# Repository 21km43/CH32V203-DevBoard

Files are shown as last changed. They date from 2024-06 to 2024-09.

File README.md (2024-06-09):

# CH32V203 Development Board

## Summary
Schematic and Board layout of CH32V203 Development Board. This project was created using [KiCAD 8](https://www.kicad.org/).

## MCU
[CH32V203C8T6](https://www.wch-ic.com/products/CH32V203.html)  
144MHz, 20KB RAM, 64KB ROM  

## Features
* CH32V203C8T6 RISC-V
* `144 MHz` maximum frequency, `64 KB` of Flash memory, `20 KB` of SRAM
* `8 MHz` crystal (High-Speed Enternal Clock)
* `32.768 KHz` crystal (Low-Speed External Clock)
* Frequency deviation of crystal has been tested (on FR-4 board with a thickness of 1.6 mm)
* White LED for `PC13`
* 2x20 side pins
* Size: `50.80 mm x 20.32 mm`
* USB Device (Type-C)
  * PA11 USB1_DM
  * PA12 USB1_DP
* USB Host (Type-C)
  * PB6 USB2_DM
  * PB7 USB2_DP
* All component parameters are already set for [JLCPCB](https://jlcpcb.com). (Thanks for [Fabrication Toolkit](https://github.com/bennymeg/Fabrication-Toolkit))
  * Tooling Hole for SMT Assembly has been added.

## Solder jumpers
* JP1 ... If this jumper is opened, 3.3V cannot be output from the USB or 5V pins through the LDO regulator, and power must be supplied to the MCU from 3.3V. Instead, the quiescent current of the LDO regulator can be set to 0, which optimizes power consumption.
* JP2 ... Shorting this jumper disables the back-flow protection from the 5V pin to the USB input; short it when you want to output 5V from the USB to 5V with no voltage drop or when you want to use the 5V pin to power the USB2 output. Do not supply power from both the 5V pin and USB while shorted. Note that shorting this pin will increase current consumption by about 0.1~0.2mA due to the pull-down resistor on the CC pin.
* JP3 ... Shorting all of these jumpers changes the function of USB2 from Host to Device and allows it to receive power from USB2. In this case, it is not recommended to use USB1 and USB2 at the same time (because of the risk of short circuits if the voltages of USB1 and USB2 are different)

## Parts List
You can see parts list from the BOM below.  
[Parts List](/production/bom.csv)

## Schematic and Board image
[Board schematic](CH32V203-DevBoard.pdf)  
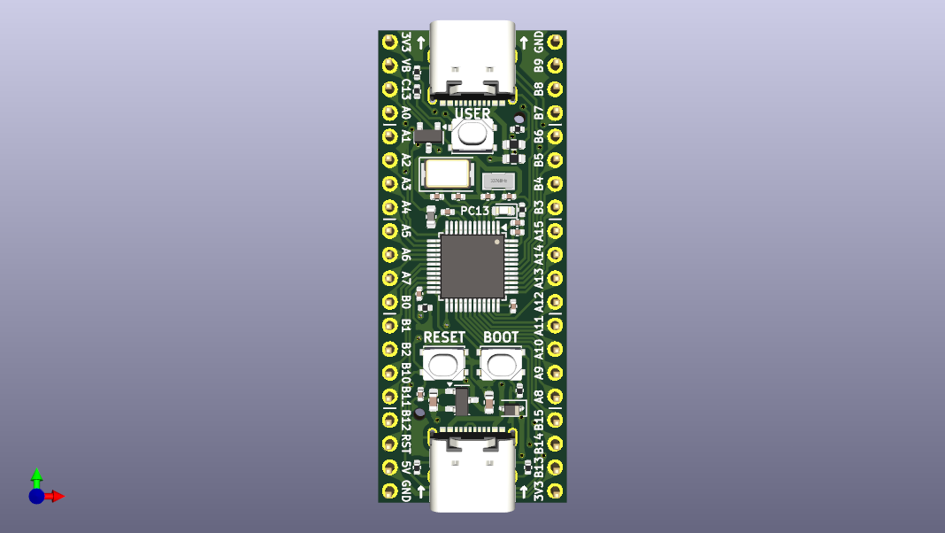
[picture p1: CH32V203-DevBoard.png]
Board Image


## LICENSE
[MIT LICENSE](/LICENSE)  
You may use it freely for personal use, but if you wish to use it for commercial purposes, I would appreciate it if you could contact me.

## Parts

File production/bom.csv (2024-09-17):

Designator | Footprint | Quantity | Value | LCSC Part #
C1, C2 | 0402 | 2 | 15pF | C1548
C10, C5, C6, C7, C8, C9 | 0402 | 6 | 100nF | C1525
C11, C12 | 0603 | 2 | 1uF | C15849
C3, C4 | 0402 | 2 | 22pF | C1555
D1 | D_SOD-323 | 1 | 1N5819WS | C191023
D2 | SOT-23 | 1 | BAT54C,215 | C37704
FB1 | 0603 | 1 | FerriteBead | C1002
J1, J2 | USB_C_Receptacle_XKB_U262-16XN-4BVC11 | 2 | USB_C_Receptacle_USB2.0_16P | C2988369
LED1 | 0603 | 1 | LED | C2290
R1, R2, R8 | 0402 | 3 | 10kΩ | C25744
R10, R11, R3, R4, R5 | 0402 | 5 | 5.1kΩ | C25905
R6, R7 | 0603 | 2 | 56kΩ | C23206
SW1, SW2, SW3 | SW_SPST_PTS810 | 3 | SW_Push | C115360
U1 | LQFP-48_7x7mm_P0.5mm | 1 | CH32V203C8T6 | C3001172
U2 | SOT-23-3 | 1 | XC6206P332MR | C5446
XTAL1 | Crystal_SMD_3215-2Pin_3.2x1.5mm | 1 | 32.768KHz | C32346
XTAL2 | Crystal_SMD_5032-2Pin_5.0x3.2mm | 1 | 8MHz | C115962

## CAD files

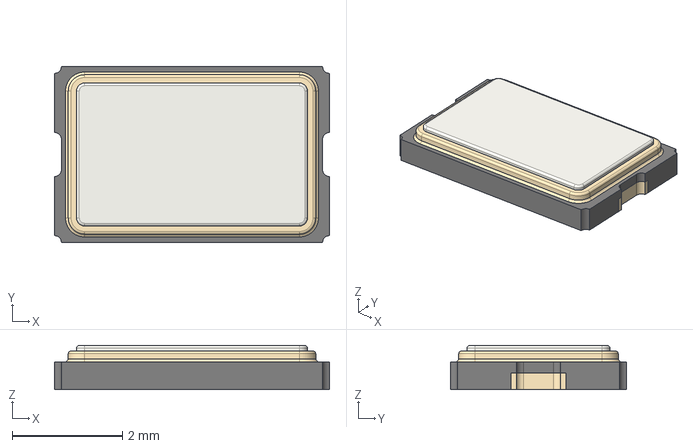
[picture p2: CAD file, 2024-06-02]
3d/5032_crystal_oscillator.step
5.00 x 3.20 x 0.8 mm

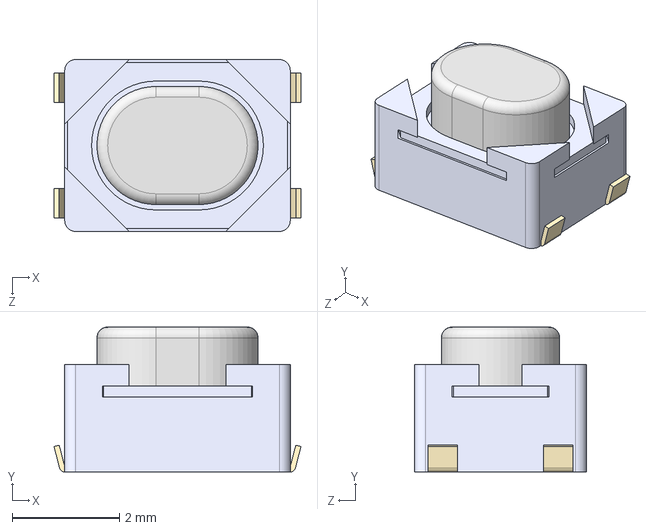
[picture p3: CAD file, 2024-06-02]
3d/PTS810.STEP
4.60 x 2.70 x 3.20 mm

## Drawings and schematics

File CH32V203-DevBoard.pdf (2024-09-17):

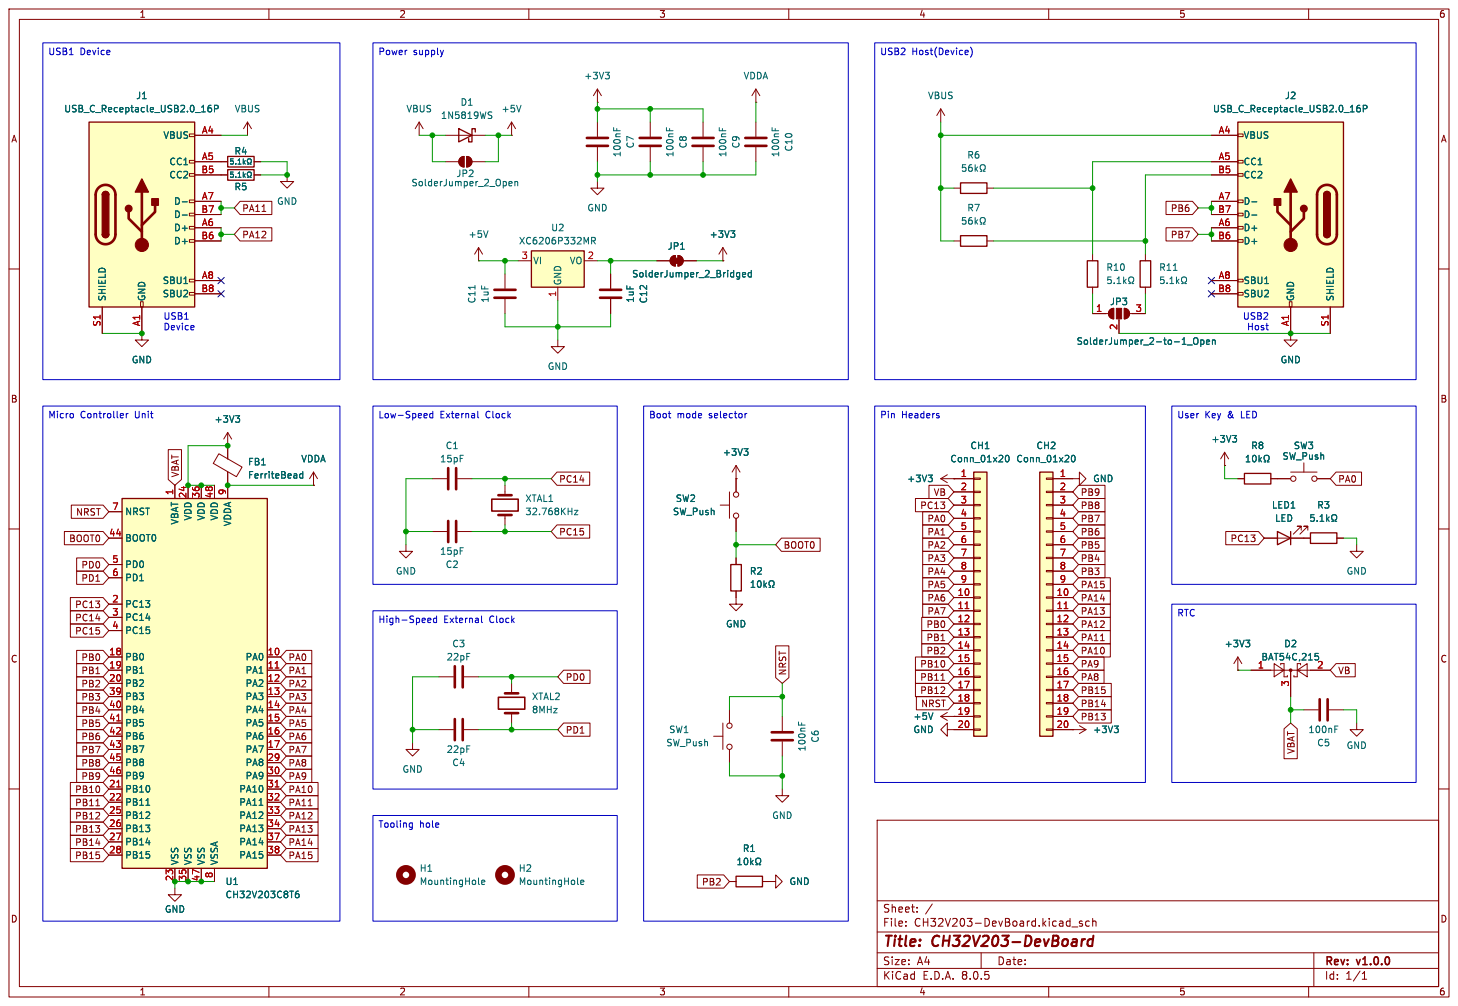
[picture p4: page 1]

1 PA0 10 PA1 11 PA2 12 PA3 13 PA4 14 PA5 15 PA6 16 PA7 17 PB0 18 PB1 19 PC13 2 PB2 20 PB10 21 PB11 22 VSS 23 VDD 24 PB12 25 PB13 26 PB14 27 PB15 28 PA8 29 PC14 3 PA9 30 PA10 31 PA11 32 PA12 33 PA13 34 VSS 35 VDD 36 PA14 37 PA15 38 PB3 39 PC15 4 PB4 40 PB5 41 PB6 42 PB7 43 BOOT0 44 PB8 45 PB9 46 VSS 47 VDD 48 PD0 5 PD1 6 NRST 7 VSSA

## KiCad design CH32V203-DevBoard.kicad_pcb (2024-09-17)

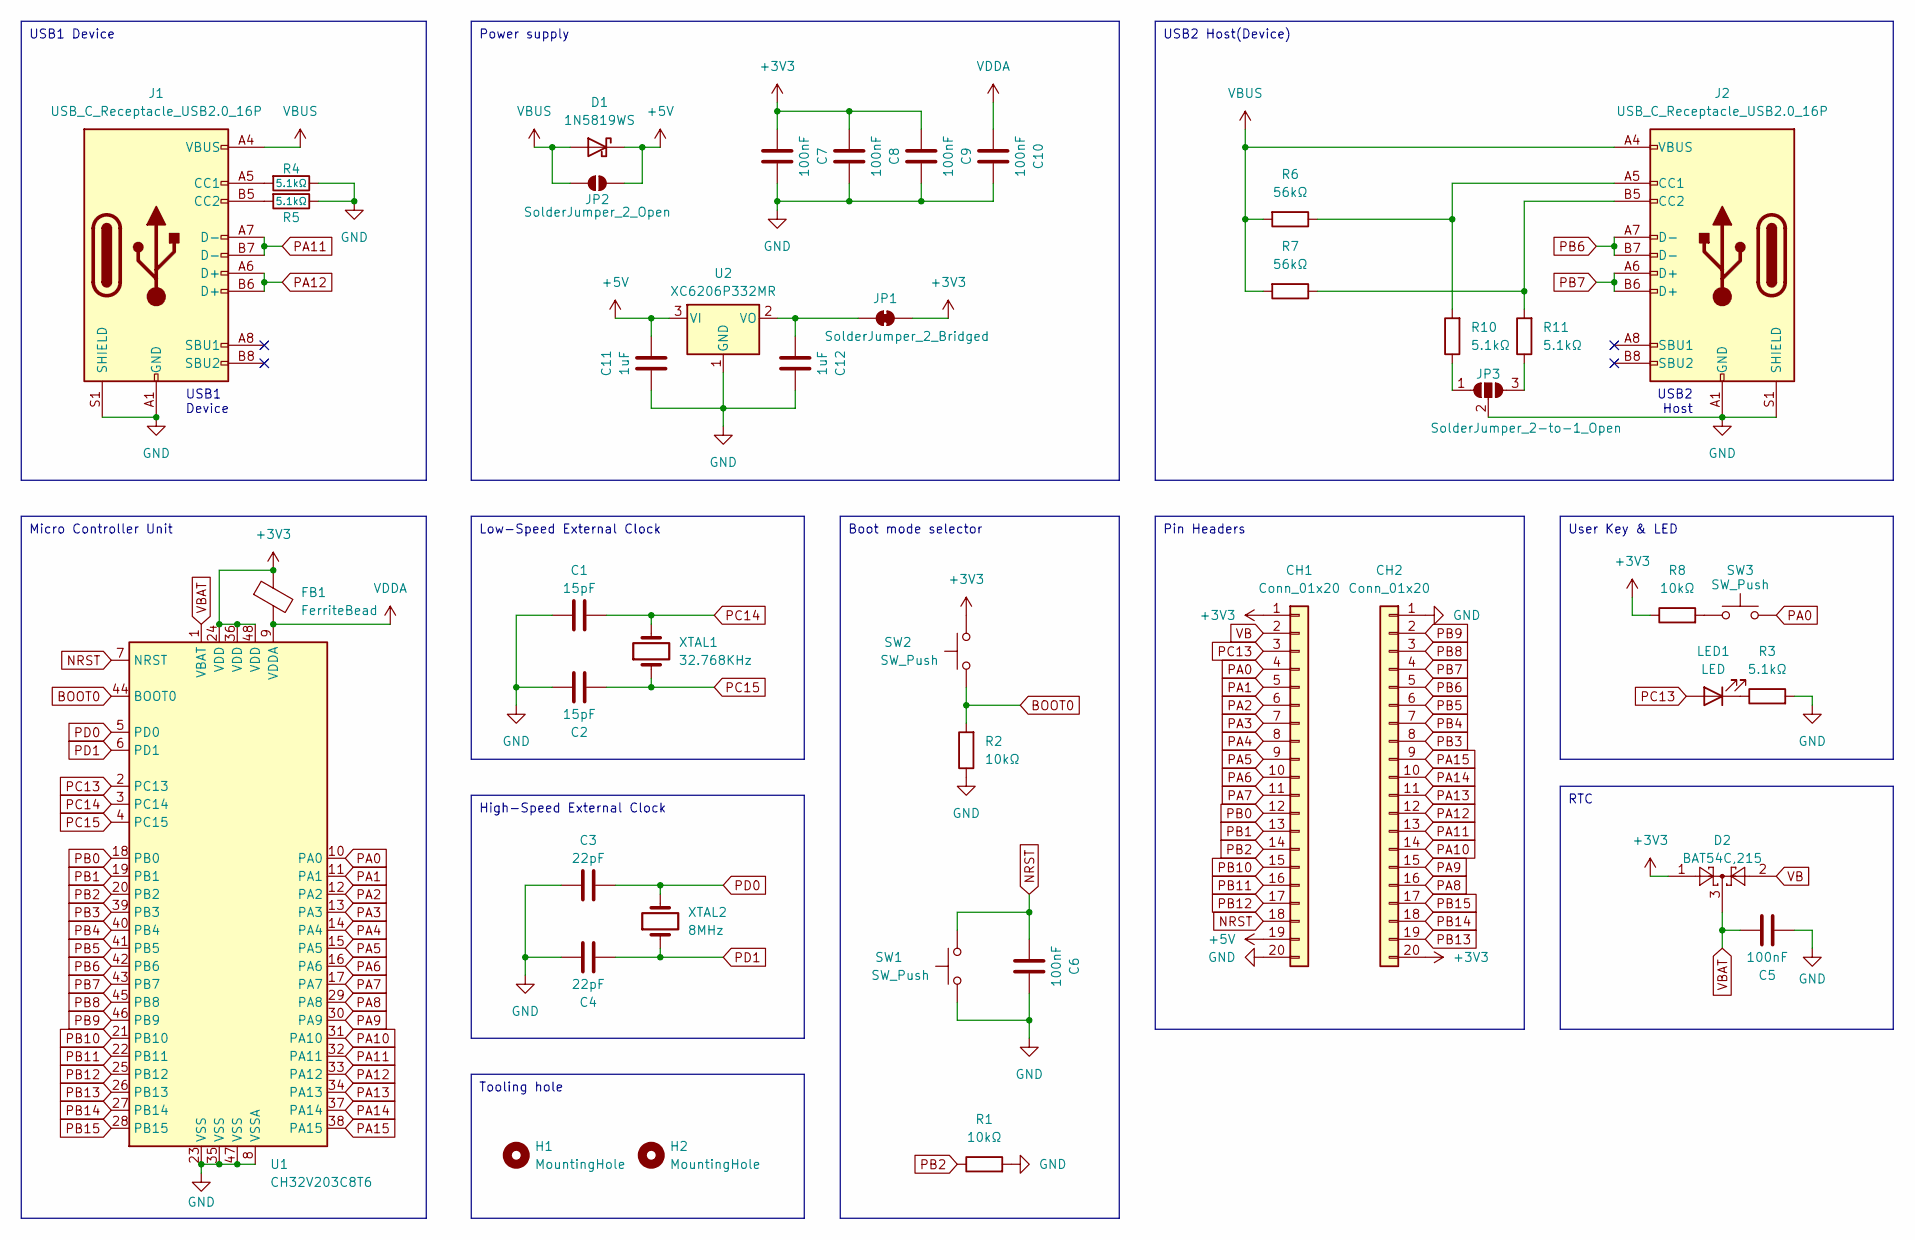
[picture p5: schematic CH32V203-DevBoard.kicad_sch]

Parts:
C1, C2: 15pF; C_0402_1005Metric; LCSC C1548
C3, C4: 22pF; C_0402_1005Metric; LCSC C1555
C5, C6, C7, C8, C9, C10: 100nF; C_0402_1005Metric; LCSC C1525
C11, C12: 1uF; C_0603_1608Metric; LCSC C15849
CH1, CH2: Conn_01x20; PinHeader_1x20_P2.54mm_Vertical
D1: 1N5819WS; D_SOD-323; LCSC C191023
D2: BAT54C,215; SOT-23; LCSC C37704
FB1: FerriteBead; L_0603_1608Metric; LCSC C1002
H1, H2: MountingHole; Tooling_Hole
J1, J2: USB_C_Receptacle_USB2.0_16P; USB_C_Receptacle_XKB_U262-16XN-4BVC11; LCSC C2988369
JP1: SolderJumper_2_Bridged; SolderJumper-2_P1.3mm_Bridged_RoundedPad1.0x1.5mm
JP2: SolderJumper_2_Open; SolderJumper-2_P1.3mm_Open_RoundedPad1.0x1.5mm
JP3: SolderJumper_2-to-1_Open; SolderJumper-2-to-1_P0.9mm_Open
LED1: LED; LED_0603_1608Metric; LCSC C2290
R1, R2, R8: 10kΩ; R_0402_1005Metric; LCSC C25744
R3, R4, R5, R10, R11: 5.1kΩ; R_0402_1005Metric; LCSC C25905
R6, R7: 56kΩ; R_0603_1608Metric; LCSC C23206
SW1, SW2, SW3: SW_Push; SW_SPST_PTS810; LCSC C115360
U1: CH32V203C8T6; LQFP-48_7x7mm_P0.5mm; LCSC C3001172
U2: XC6206P332MR; SOT-23-3; LCSC C5446
XTAL1: 32.768KHz; Crystal_SMD_3215-2Pin_3.2x1.5mm; LCSC C32346
XTAL2: 8MHz; Crystal_SMD_5032-2Pin_5.0x3.2mm; LCSC C115962

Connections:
+3V3: C7.1, C8.1, C9.1, CH1.1, CH2.20, D2.1, FB1.1, JP1.2 (B), R8.1, SW2.2, U1.24 (VDD), U1.36 (VDD), U1.48 (VDD)
+5V: C11.1, CH1.19, D1.1 (K), JP2.2 (B), U2.3 (VI)
BOOT0: R2.2, SW2.1, U1.44 (BOOT0)
GND: C1.1, C2.2, C3.1, C4.2, C5.1, C6.2, C7.2, C8.2, C9.2, C10.2, C11.2, C12.2, CH1.20, CH2.1, J1.A1 (GND), J1.A12 (GND), J1.B1 (GND), J1.B12 (GND), J1.S1 (SHIELD), J2.A1 (GND), J2.A12 (GND), J2.B1 (GND), J2.B12 (GND), J2.S1 (SHIELD), JP3.2 (C), R1.2, R2.1, R3.2, R4.1, R5.1, SW1.1, U1.8 (VSSA), U1.23 (VSS), U1.35 (VSS), U1.47 (VSS), U2.1 (GND)
NRST: C6.1, CH1.18, SW1.2, U1.7 (NRST)
unnamed: J1.A5 (CC1), R4.2
unnamed: J1.B5 (CC2), R5.2
unnamed: J2.A5 (CC1), R6.1, R10.2
unnamed: J2.B5 (CC2), R7.1, R11.2
unnamed: C12.1, JP1.1 (A), U2.2 (VO)
unnamed: JP3.1 (A), R10.1
unnamed: JP3.3 (B), R11.1
unnamed: LED1.1 (K), R3.1
unnamed: R8.2, SW3.1
PA0: CH1.4, SW3.2, U1.10 (PA0)
PA1: CH1.5, U1.11 (PA1)
PA2: CH1.6, U1.12 (PA2)
PA3: CH1.7, U1.13 (PA3)
PA4: CH1.8, U1.14 (PA4)
PA5: CH1.9, U1.15 (PA5)
PA6: CH1.10, U1.16 (PA6)
PA7: CH1.11, U1.17 (PA7)
PA8: CH2.16, U1.29 (PA8)
PA9: CH2.15, U1.30 (PA9)
PA10: CH2.14, U1.31 (PA10)
PA11: CH2.13, J1.A7 (D-), J1.B7 (D-), U1.32 (PA11)
PA12: CH2.12, J1.A6 (D+), J1.B6 (D+), U1.33 (PA12)
PA13: CH2.11, U1.34 (PA13)
PA14: CH2.10, U1.37 (PA14)
PA15: CH2.9, U1.38 (PA15)
PB0: CH1.12, U1.18 (PB0)
PB1: CH1.13, U1.19 (PB1)
PB2: CH1.14, R1.1, U1.20 (PB2)
PB3: CH2.8, U1.39 (PB3)
PB4: CH2.7, U1.40 (PB4)
PB5: CH2.6, U1.41 (PB5)
PB6: CH2.5, J2.A7 (D-), J2.B7 (D-), U1.42 (PB6)
PB7: CH2.4, J2.A6 (D+), J2.B6 (D+), U1.43 (PB7)
PB8: CH2.3, U1.45 (PB8)
PB9: CH2.2, U1.46 (PB9)
PB10: CH1.15, U1.21 (PB10)
PB11: CH1.16, U1.22 (PB11)
PB12: CH1.17, U1.25 (PB12)
PB13: CH2.19, U1.26 (PB13)
PB14: CH2.18, U1.27 (PB14)
PB15: CH2.17, U1.28 (PB15)
PC13: CH1.3, LED1.2 (A), U1.2 (PC13)
PC14: C1.2, U1.3 (PC14), XTAL1.2
PC15: C2.1, U1.4 (PC15), XTAL1.1
PD0: C3.2, U1.5 (PD0), XTAL2.2
PD1: C4.1, U1.6 (PD1), XTAL2.1
VB: CH1.2, D2.2
VBAT: C5.2, D2.3, U1.1 (VBAT)
VBUS: D1.2 (A), J1.A4 (VBUS), J1.A9 (VBUS), J1.B4 (VBUS), J1.B9 (VBUS), J2.A4 (VBUS), J2.A9 (VBUS), J2.B4 (VBUS), J2.B9 (VBUS), JP2.1 (A), R6.2, R7.2
VDDA: C10.1, FB1.2, U1.9 (VDDA)

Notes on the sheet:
USB1 Device
Pin Headers
Tooling hole
USB2 Host(Device)
RTC
High-Speed External Clock
Micro Controller Unit
Boot mode selector
User Key & LED
Power supply
Low-Speed External Clock
USB2 Host
USB1 Device

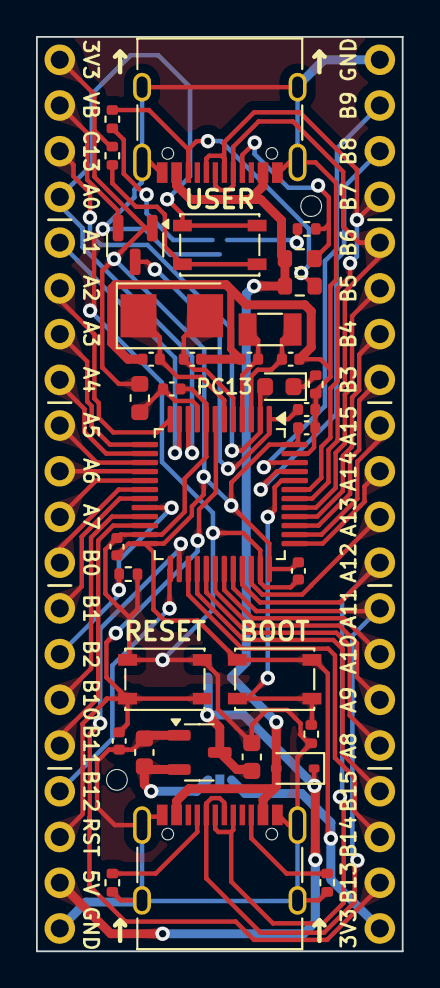
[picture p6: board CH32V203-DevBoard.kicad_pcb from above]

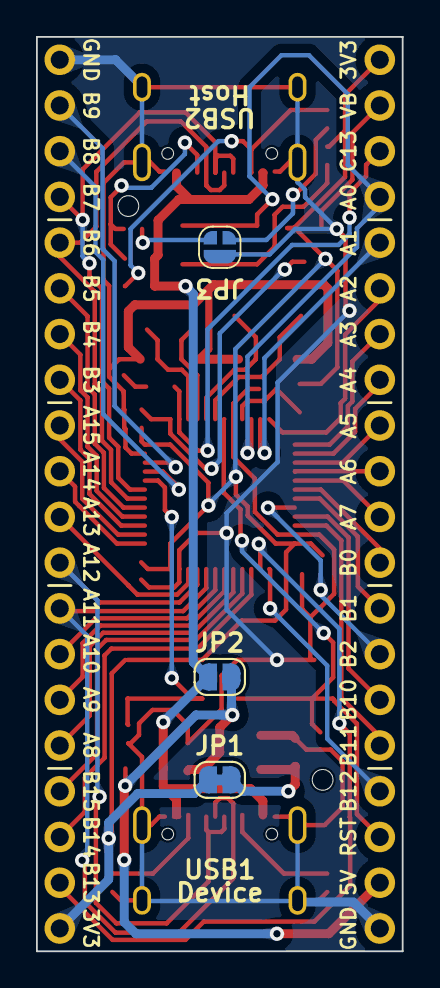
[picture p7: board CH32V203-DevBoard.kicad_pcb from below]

Board: 2 copper layers, 20.3 x 50.8 mm, 42 parts (5 on the bottom side), 55 nets.

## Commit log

2024-06-02 配線・シルクを微調整
    [CH32V203-DevBoard.kicad_pcb]
2024-06-03 USB周りの配線や裏面シルクの修正
    [CH32V203-DevBoard.kicad_pcb, CH32V203-DevBoard.kicad_sch, positions.csv]
2024-06-03 画像・gitignore更新
2024-06-06 add usb2 device solder jumper
    [CH32V203-DevBoard.kicad_pcb, CH32V203-DevBoard.kicad_sch, bom.csv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]
2024-06-06 fix JLCPCB Offset
    [CH32V203-DevBoard.kicad_pcb, CH32V203-DevBoard.kicad_sch, positions.csv]
2024-06-06 pulldown resistor fix
    [CH32V203-DevBoard.kicad_pcb, CH32V203-DevBoard.kicad_sch, bom.csv]
2024-06-06 remove unused property
    [CH32V203-DevBoard.kicad_pcb, CH32V203-DevBoard.kicad_sch]
2024-06-07 fix wire width
    [CH32V203-DevBoard.kicad_pcb, CH32V203-DevBoard.kicad_sch]
2024-06-07 show reference number
    [CH32V203-DevBoard.kicad_pcb]
2024-06-07 jp3 fix
    [CH32V203-DevBoard.kicad_pcb]
2024-06-07 jumper footprint fix
    [CH32V203-DevBoard.kicad_pcb]
2024-06-08 fix default usb position
    [CH32V203-DevBoard.kicad_pcb, CH32V203-DevBoard.kicad_sch, positions.csv]
2024-06-08 change usb component
    [CH32V203-DevBoard.kicad_pcb, CH32V203-DevBoard.kicad_sch, bom.csv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]
2024-07-11 change ldo and add PA0 switch
    [CH32V203-DevBoard.kicad_pcb, CH32V203-DevBoard.kicad_sch, bom.csv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]
2024-09-17 USBFS resistor fix
    [CH32V203-DevBoard.kicad_pcb, CH32V203-DevBoard.kicad_sch, bom.csv]
